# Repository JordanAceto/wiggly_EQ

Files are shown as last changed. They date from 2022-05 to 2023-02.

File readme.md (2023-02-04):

## Rackmount 3-Band Parametric EQ and Compression FX unit

### [SCHEMATIC](https://github.com/JordanAceto/wiggly_EQ/blob/main/construction_docs/wiggly_EQ_schematic.pdf)

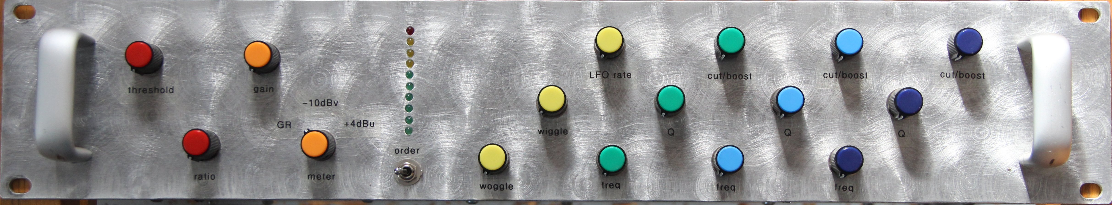
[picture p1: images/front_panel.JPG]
front panel


### Features:
#### 3 bands of Parametric EQ
- boost/cut control
- Q control
- Center frequency control
- Voltage controlled frequency for wiggly and swooshy modulation effects

#### Compression
- Nice THAT compressor
- Ratio control
- Threshold control
- Makeup gain

#### LFO
- Wiggles the EQ stages
- Also does amplitude modulation for tremolo

#### Expression pedal input
- Works as a Volume pedal
- Can also control the LFO rate

#### LED bar graph meter
- Can indicate compression gain reduction
- Can also indicate the audio level at -10dBv or +4dBu

### Notes:
- this is an old project that I built on pad-per-hole prototyping board. There is no PCB layout.
- I would probably do a few things differently today, but it does work well and sounds good.
- there are a few missing values, and some that I had to guess about, it's probably pretty close to right, but there might be some errors.
- there is a map of the protoboard IC locations as a troubleshooting and modification aid

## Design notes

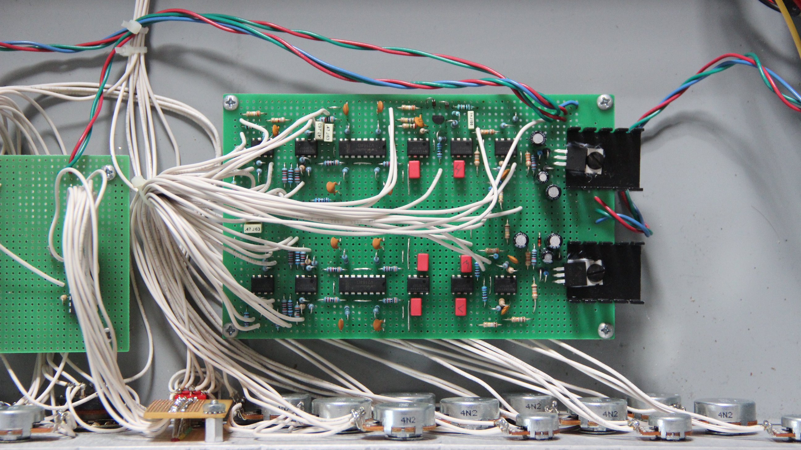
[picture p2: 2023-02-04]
images/eq_and_ps_board.JPG

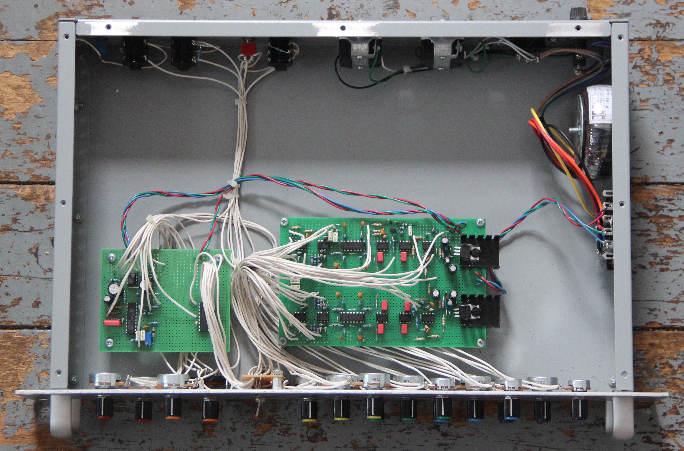
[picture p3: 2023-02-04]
images/guts_straight.JPG

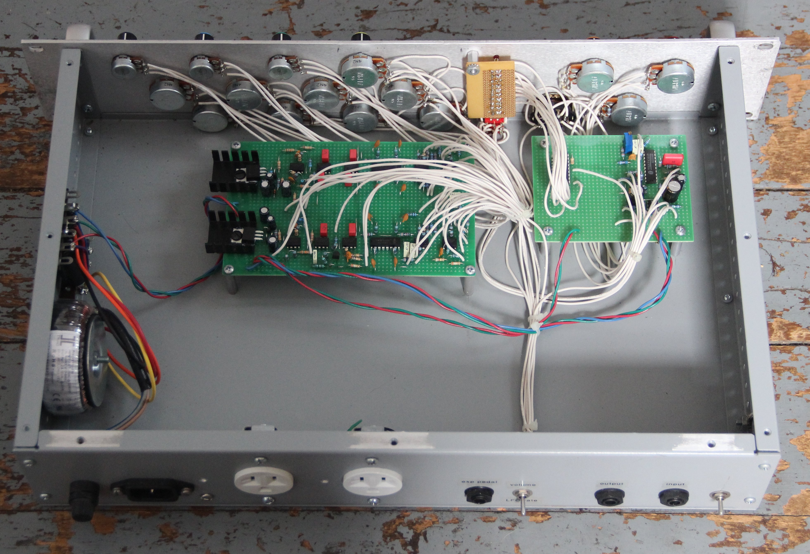
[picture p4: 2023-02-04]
images/guts_angle_2.JPG

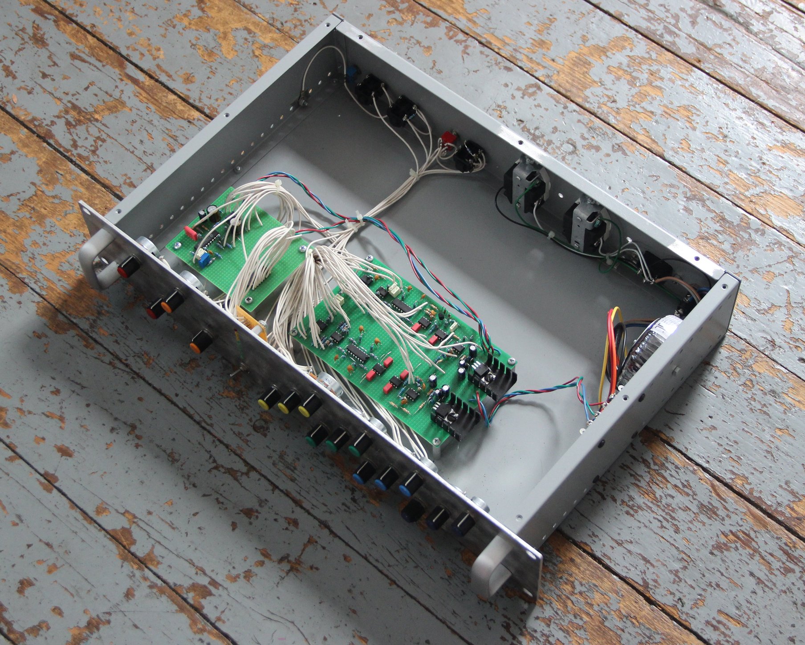
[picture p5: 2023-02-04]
images/guts_angle_1.JPG

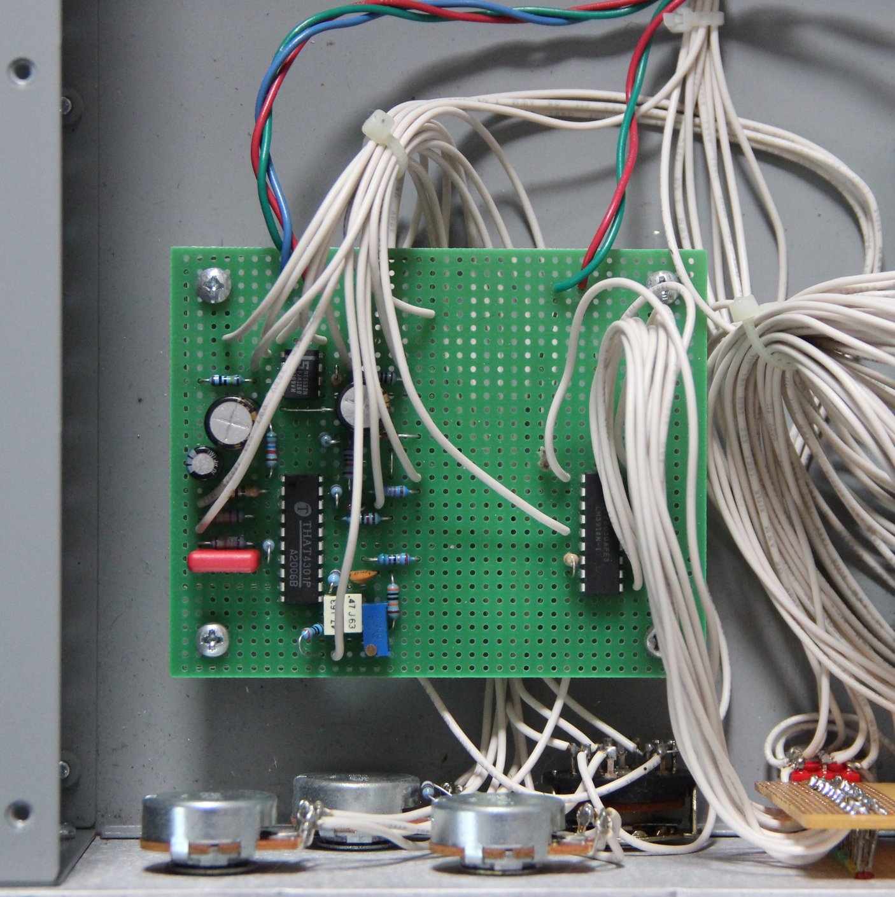
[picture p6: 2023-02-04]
images/compressor_board.JPG

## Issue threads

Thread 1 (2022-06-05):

Schematic has power supply error

JordanAceto, 2022-06-05:
The power supply schematic shows typical LM317/337 3-terminal regulators.

The connection between the V0 resistor and the ADJ pin is omitted on the schematic for both regulators.

This error should be fixed in the schematic.

The physical device is constructed correctly and works.

Closed 2022-08-01.

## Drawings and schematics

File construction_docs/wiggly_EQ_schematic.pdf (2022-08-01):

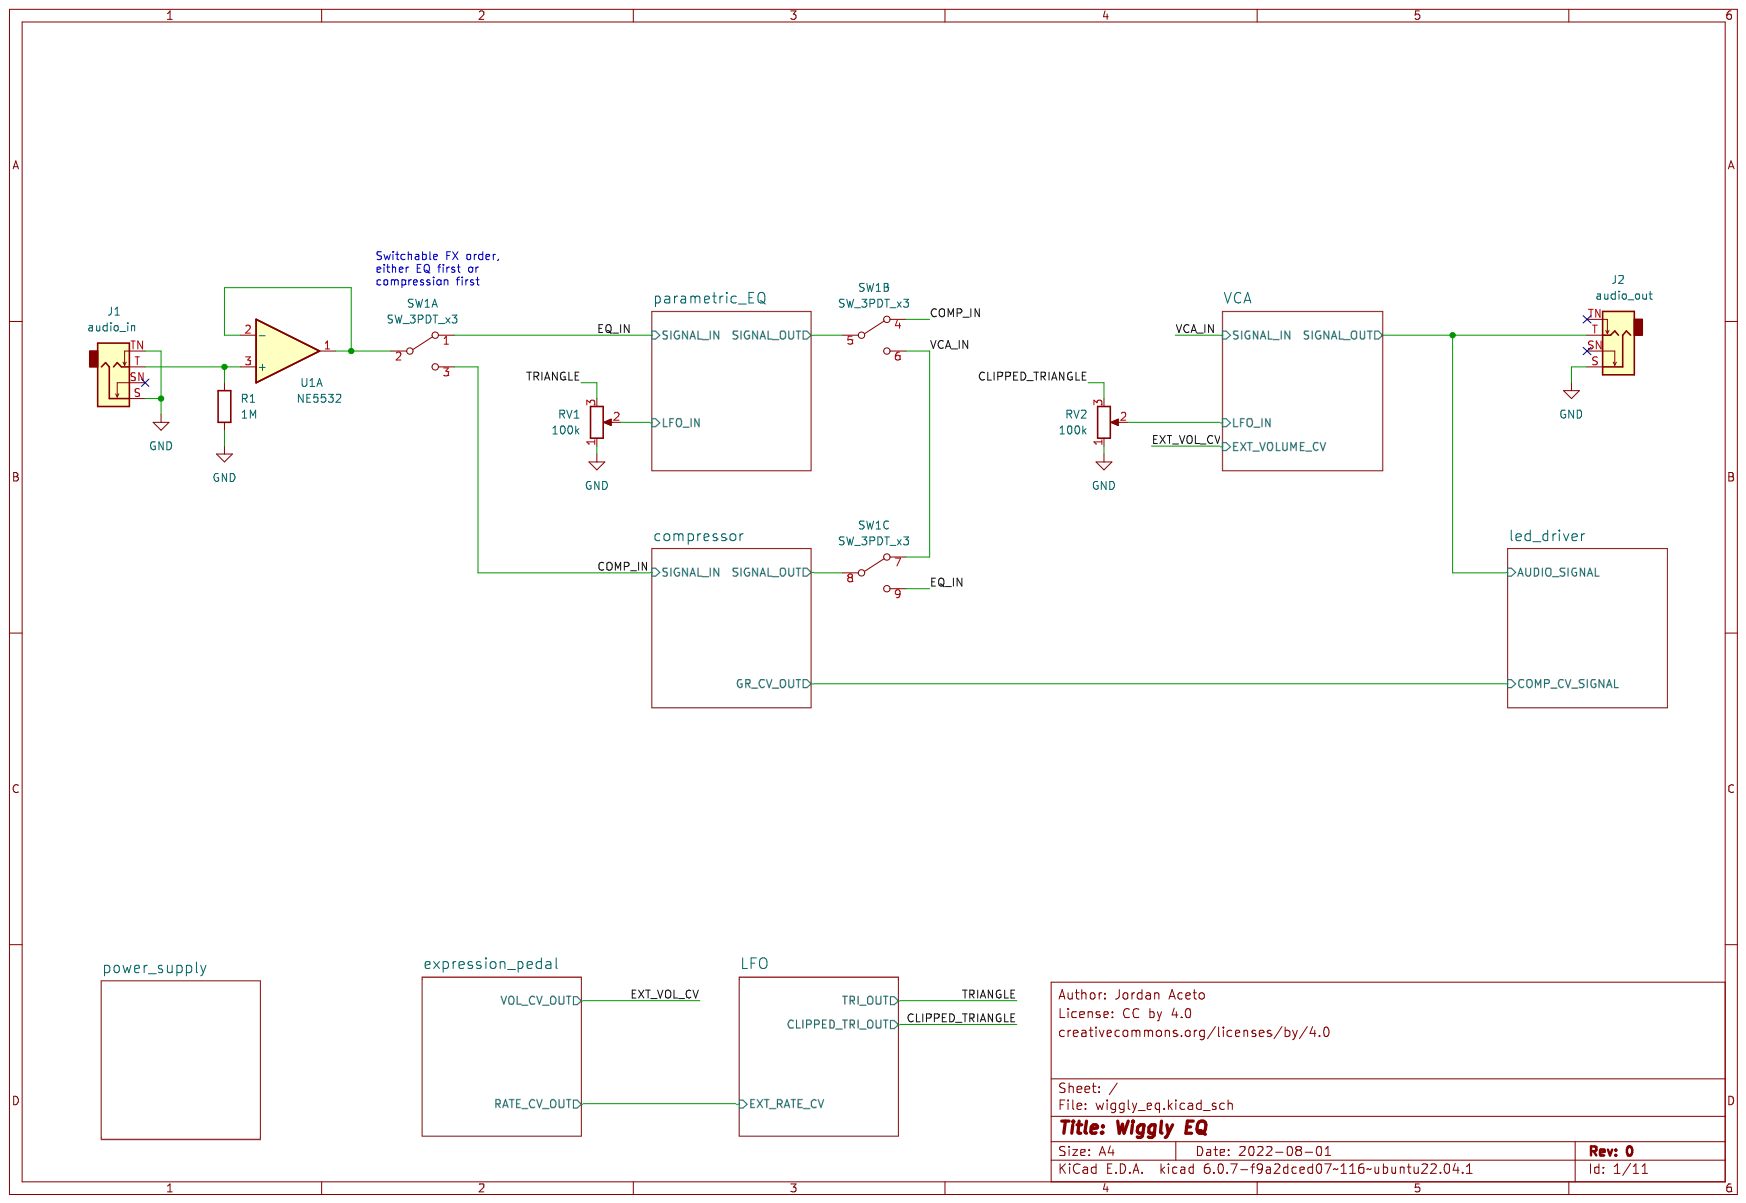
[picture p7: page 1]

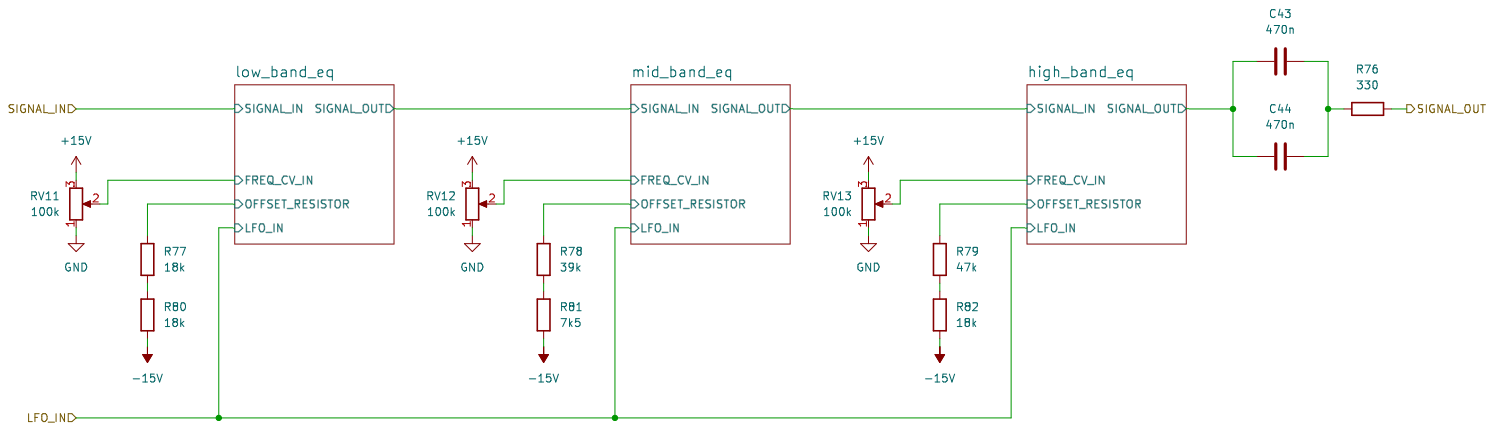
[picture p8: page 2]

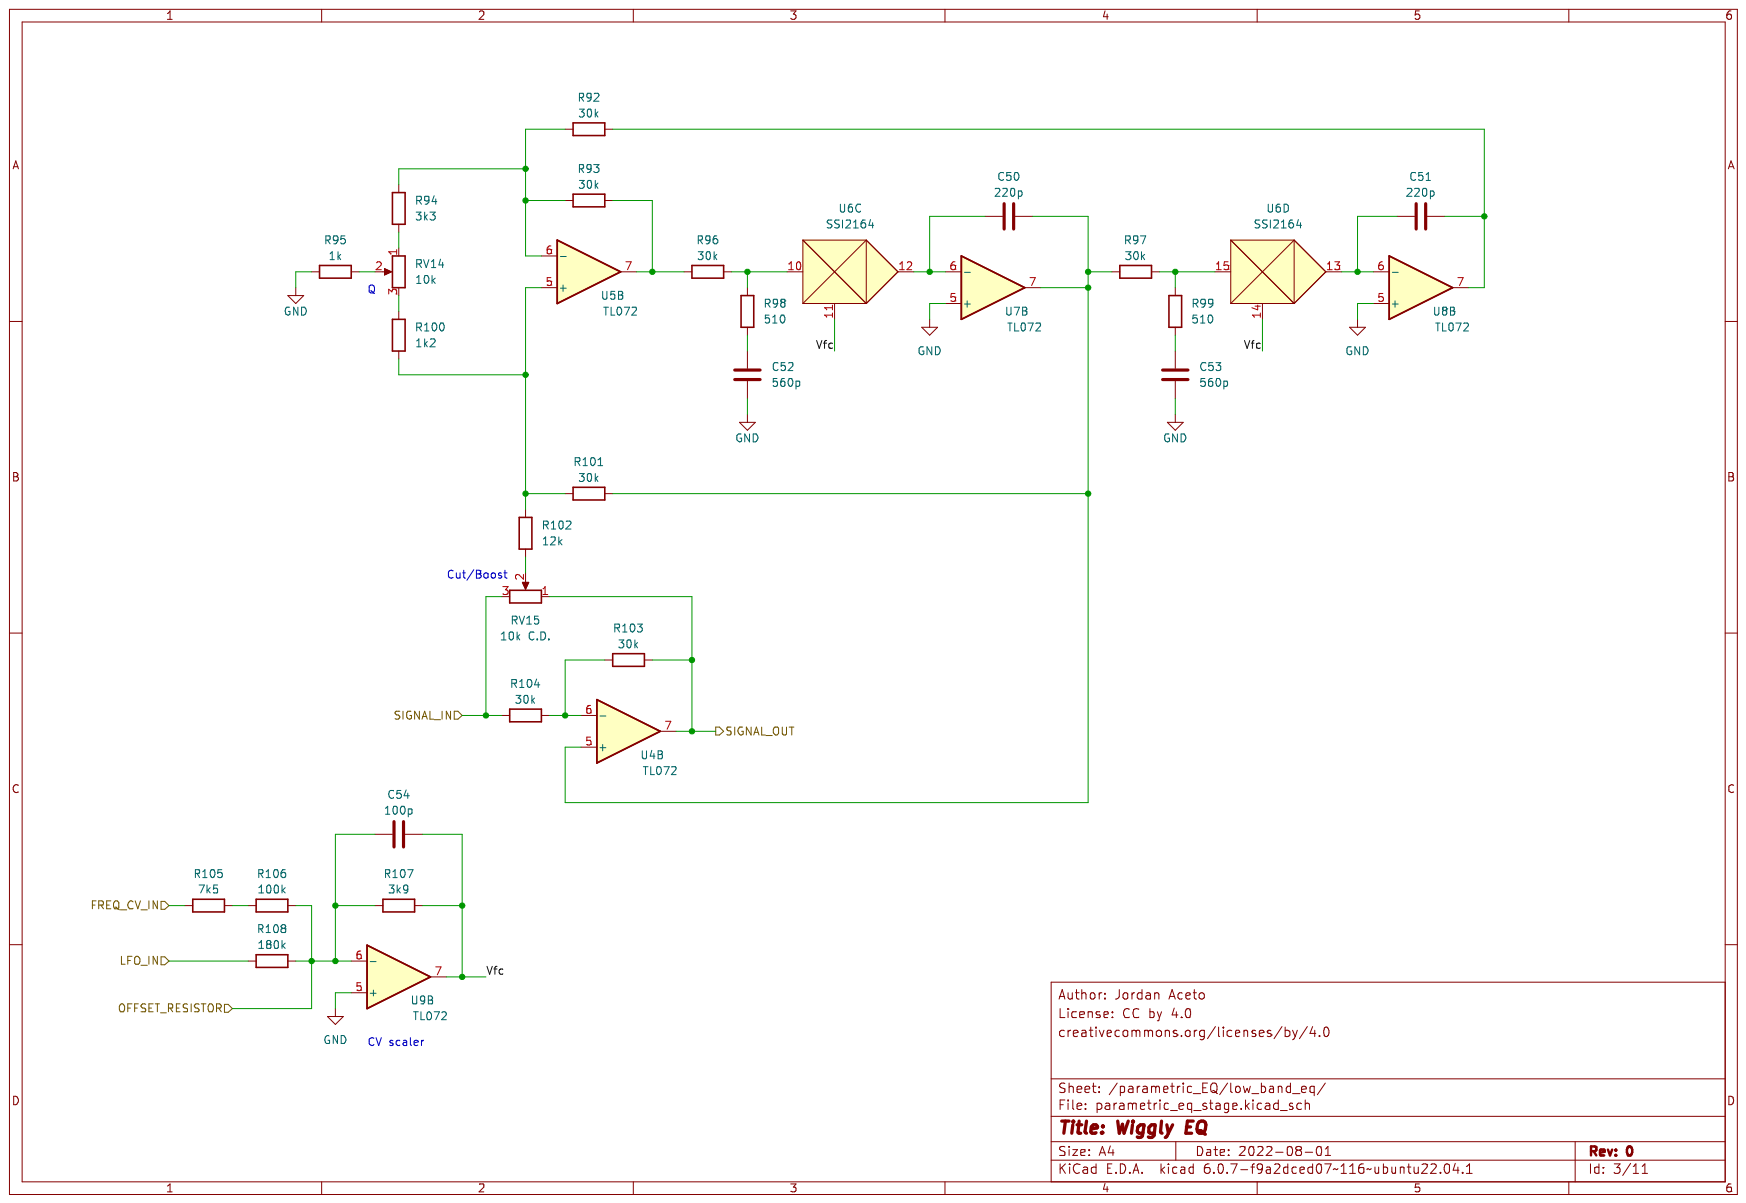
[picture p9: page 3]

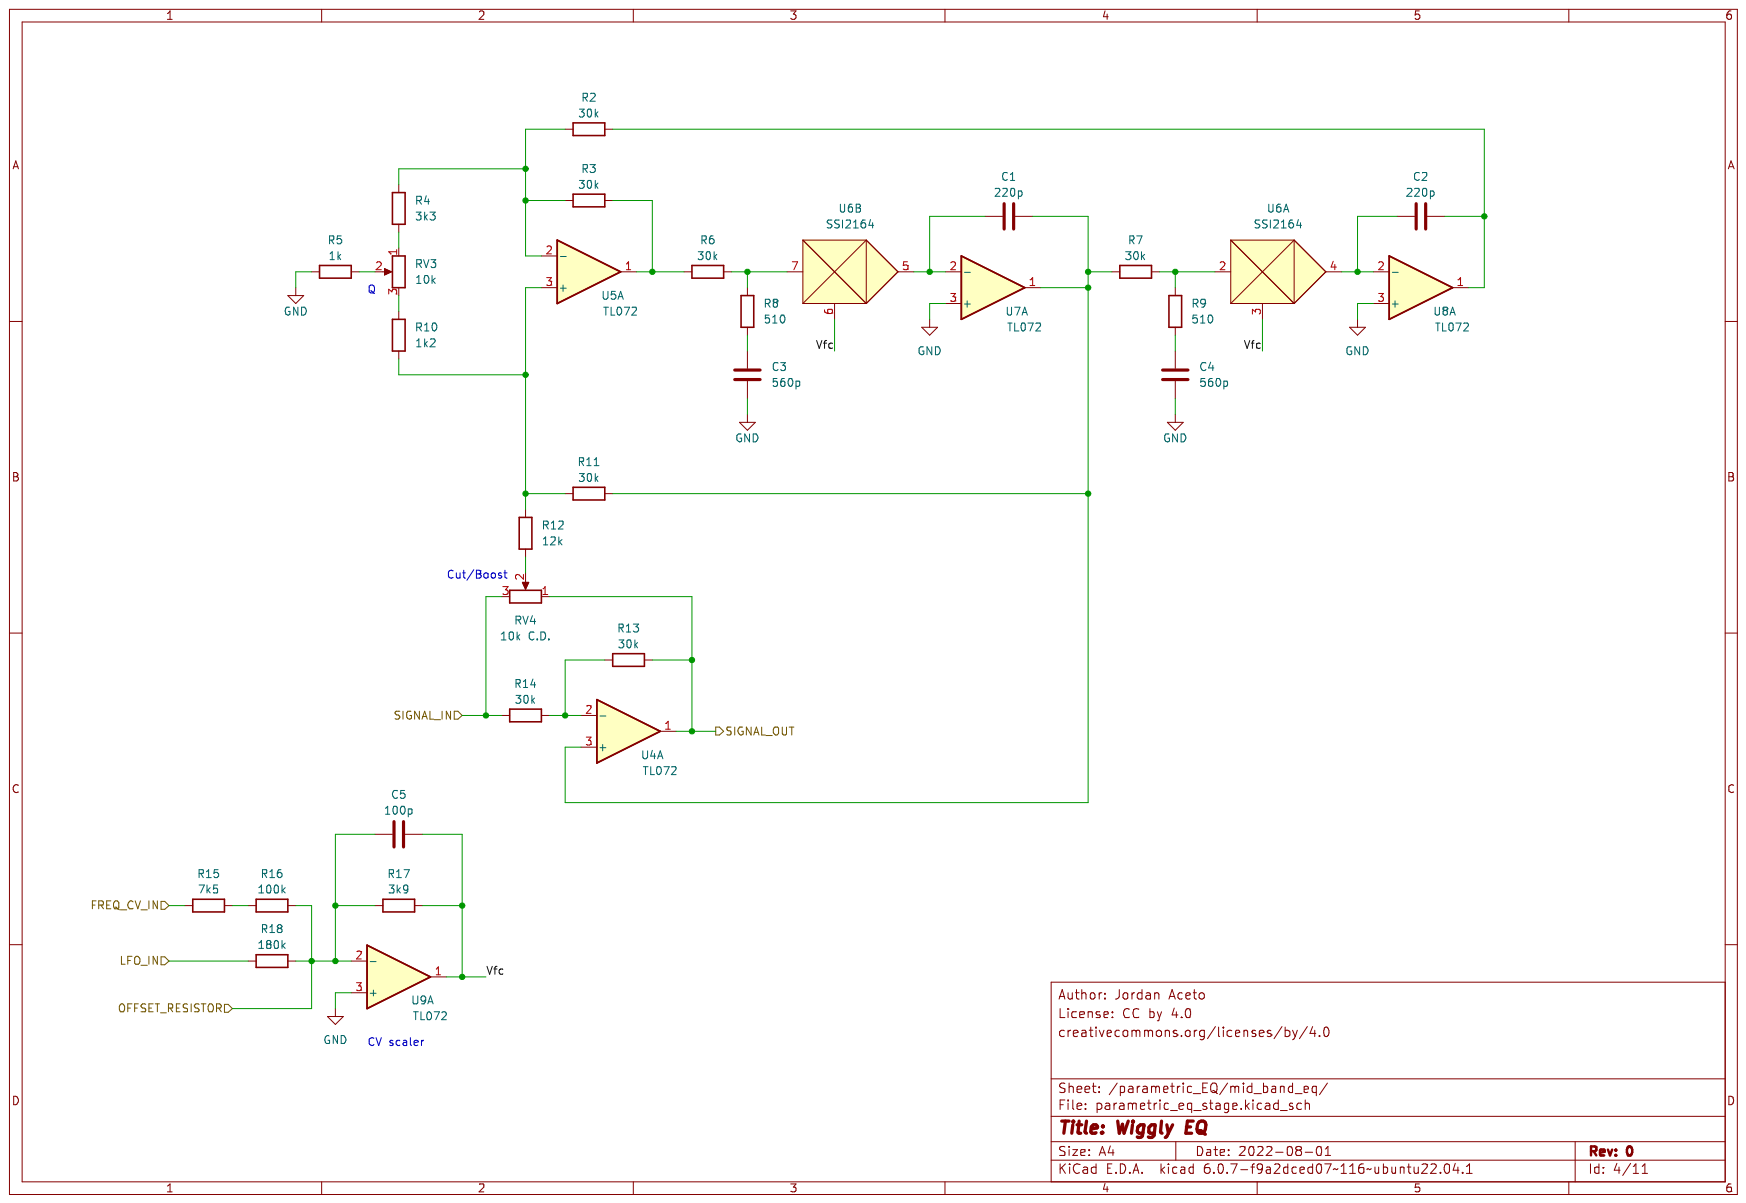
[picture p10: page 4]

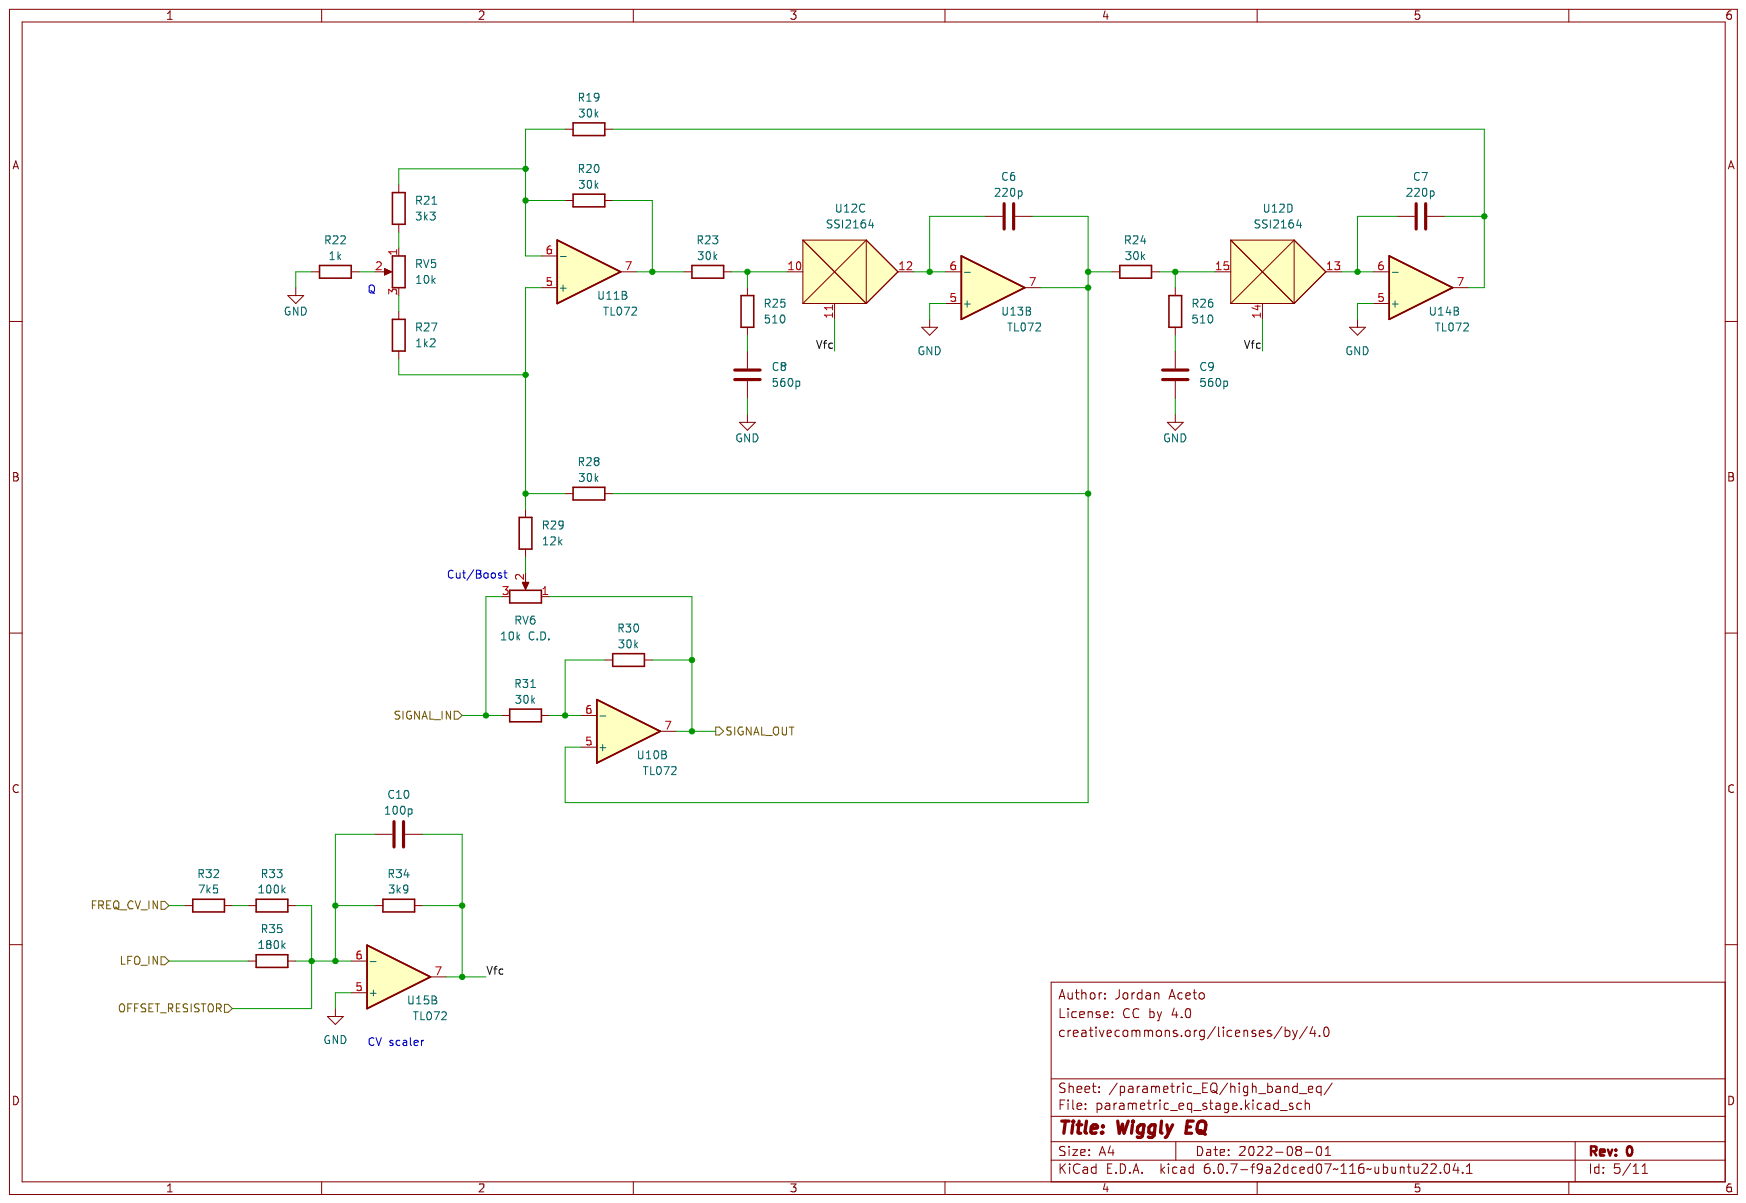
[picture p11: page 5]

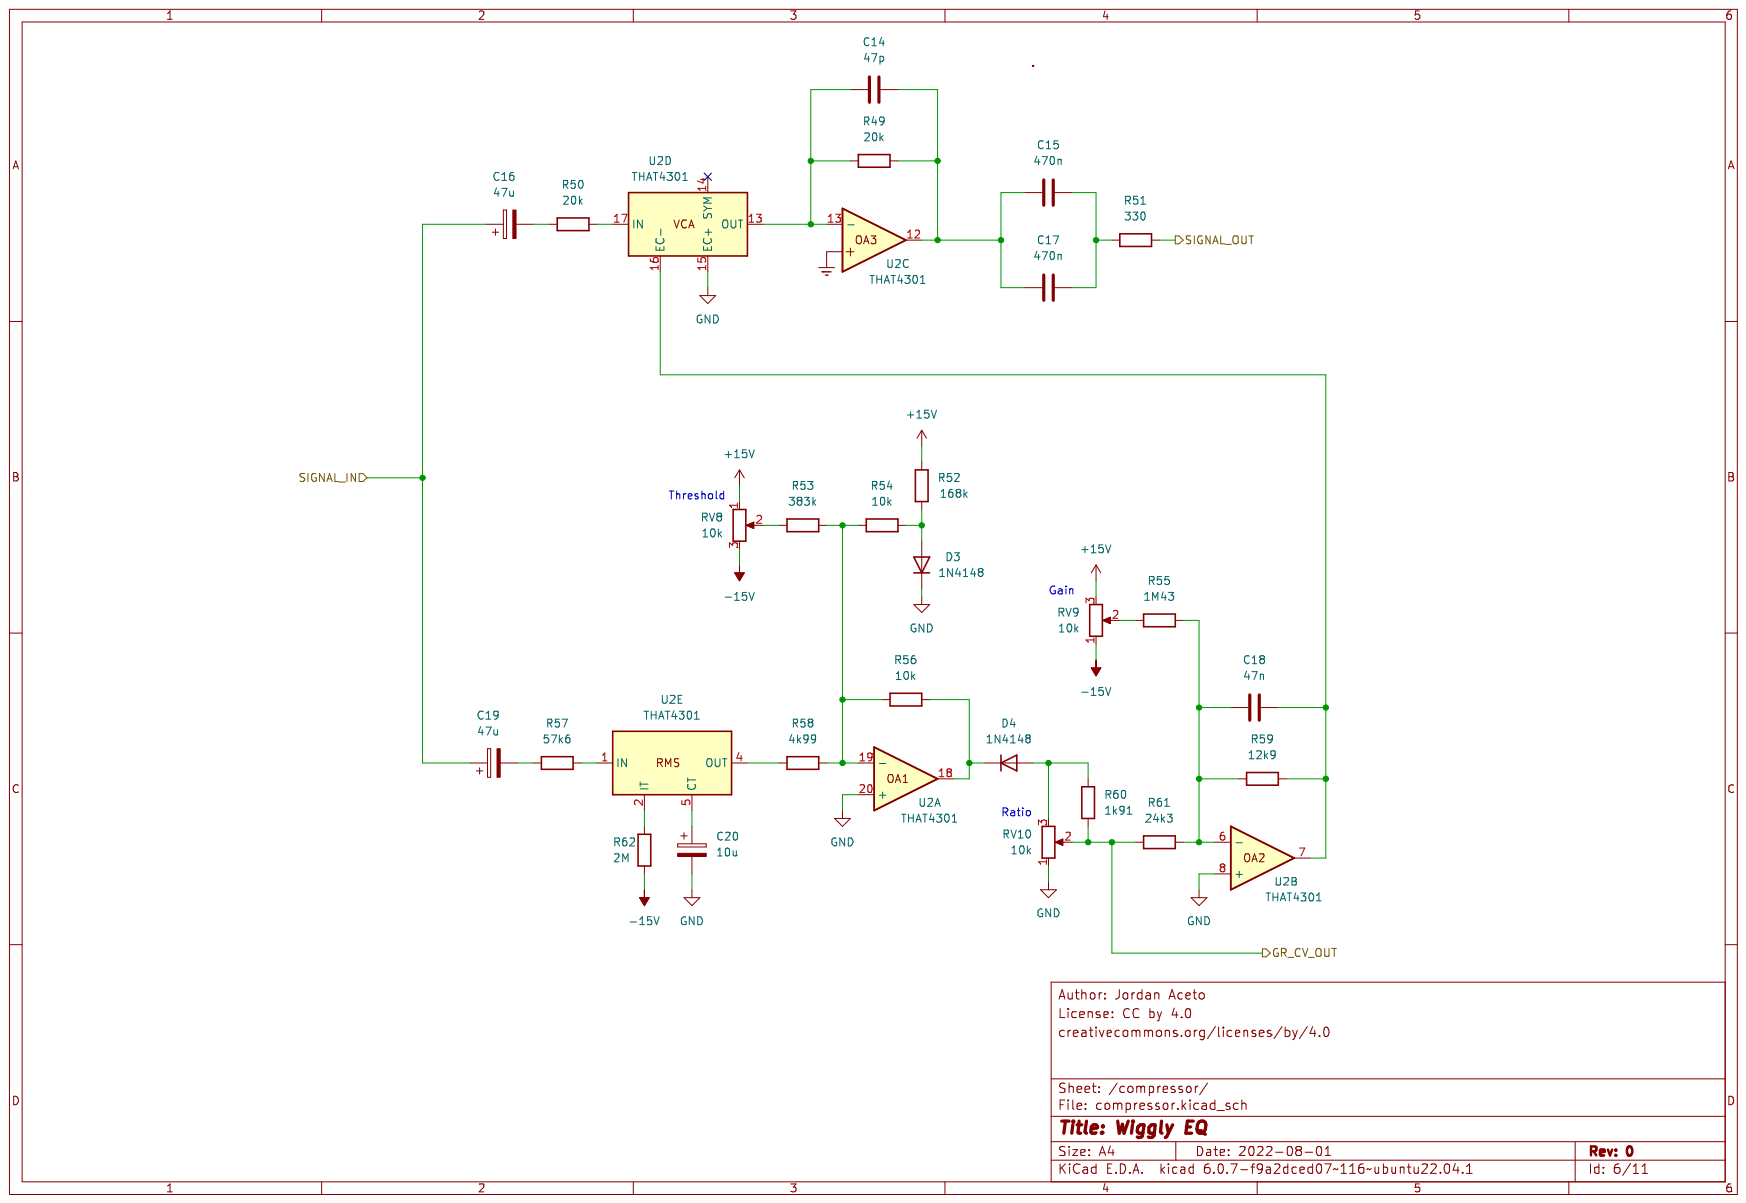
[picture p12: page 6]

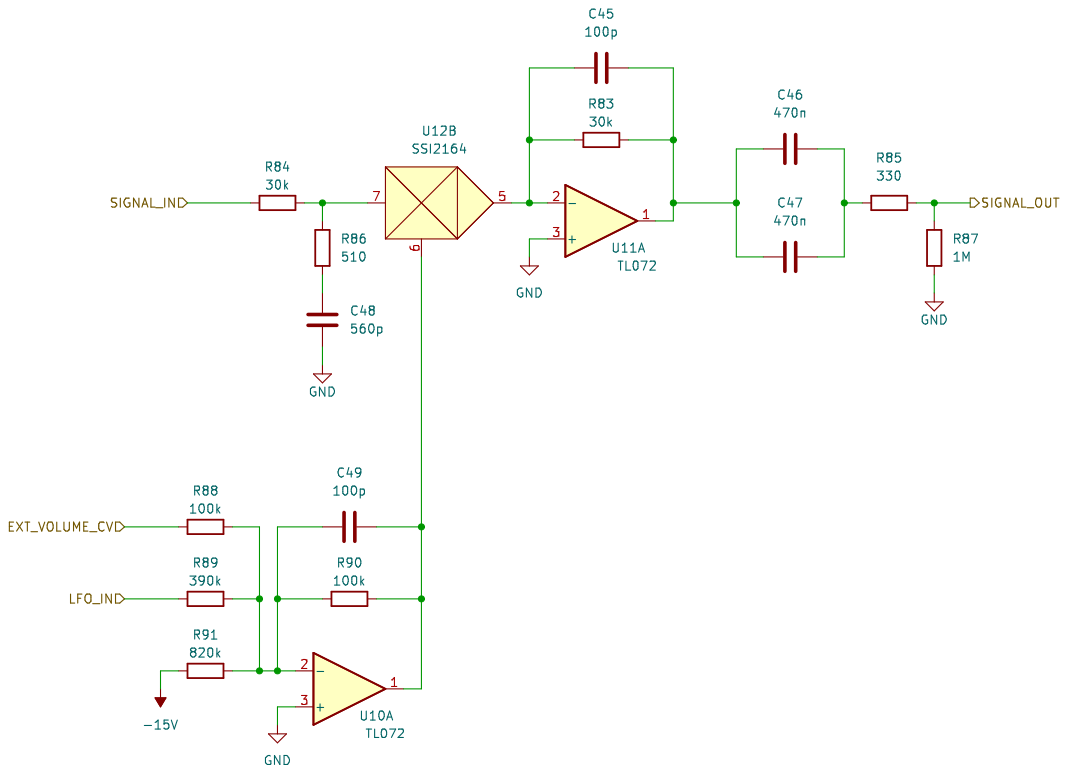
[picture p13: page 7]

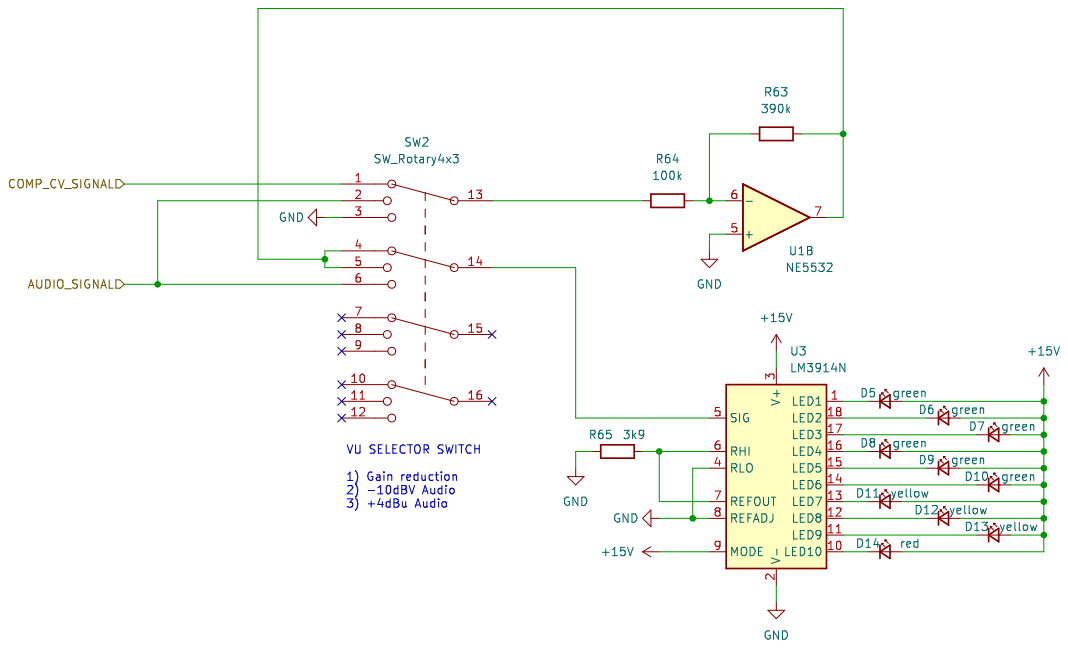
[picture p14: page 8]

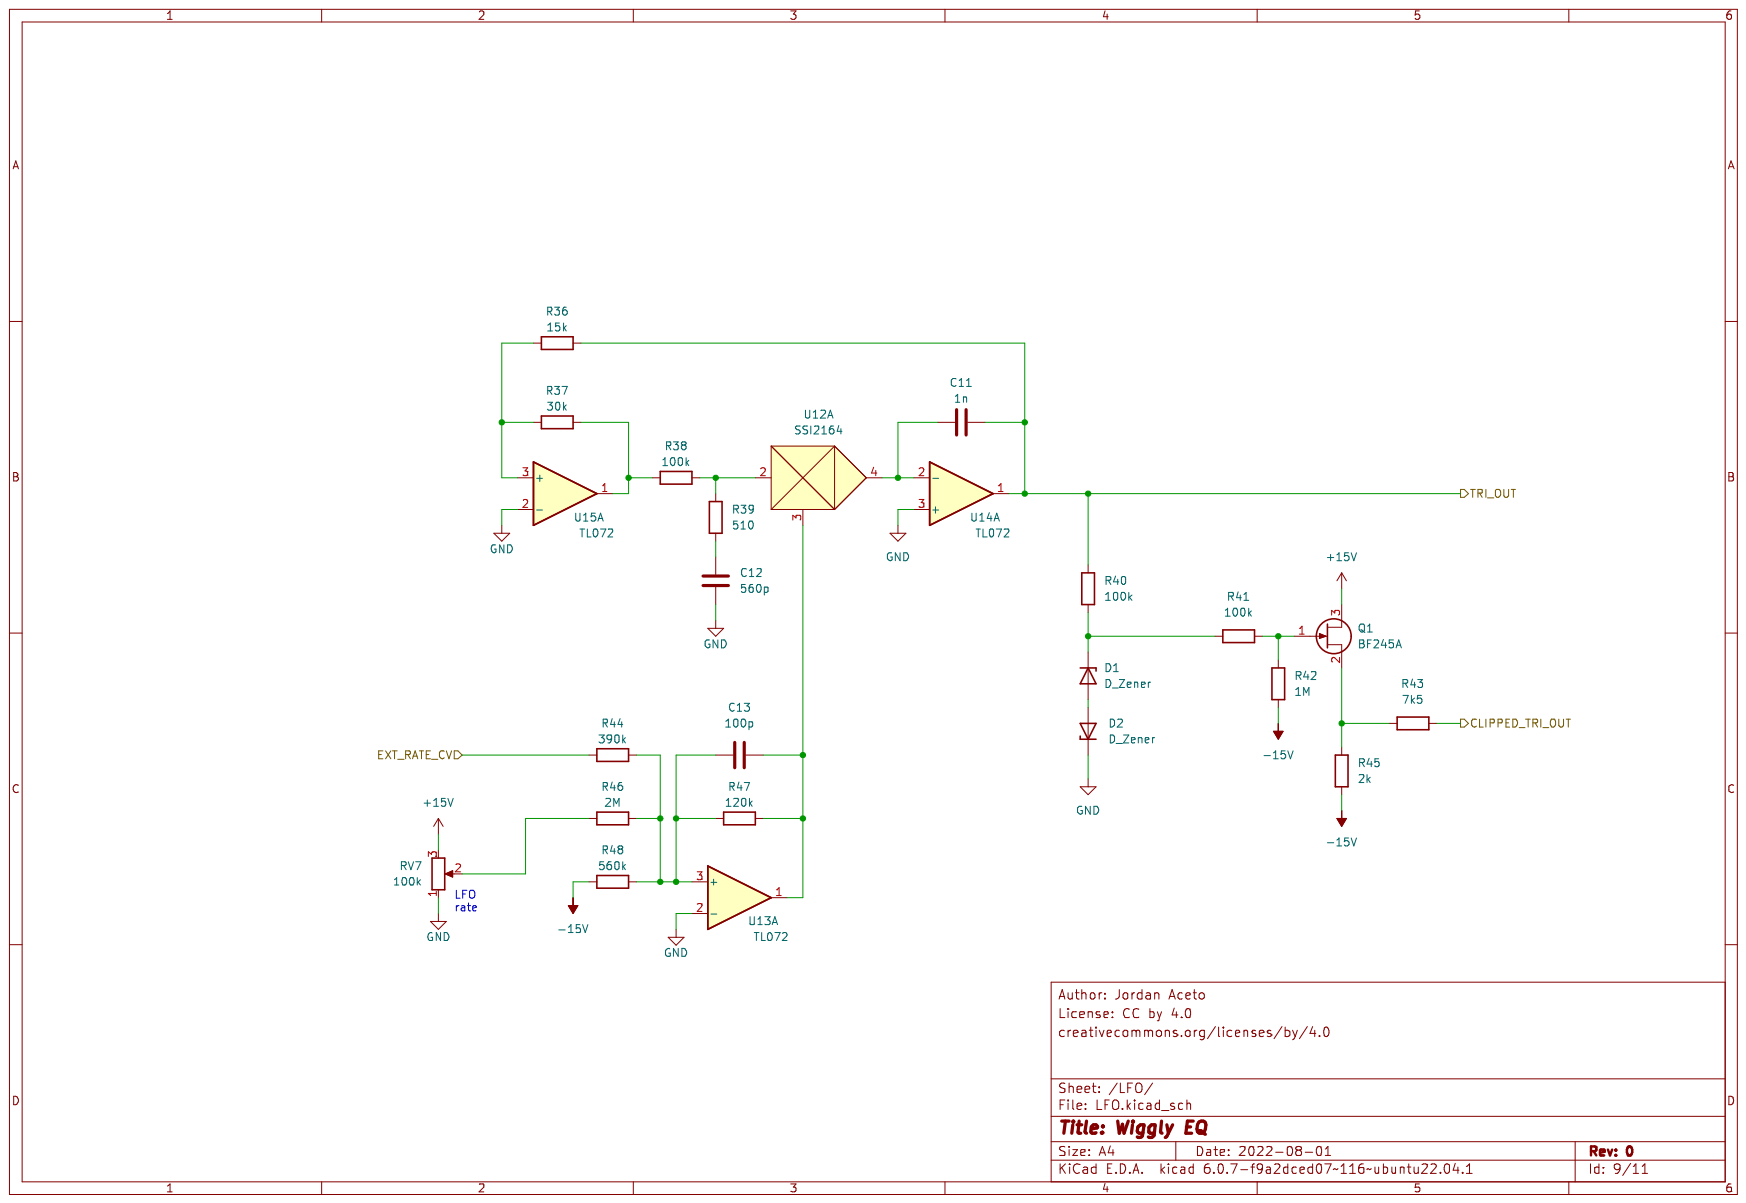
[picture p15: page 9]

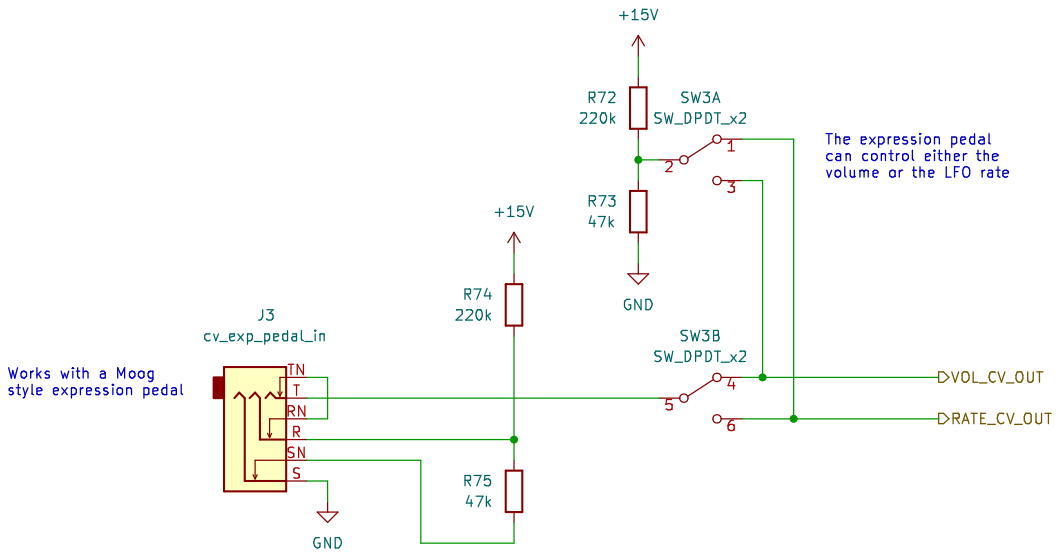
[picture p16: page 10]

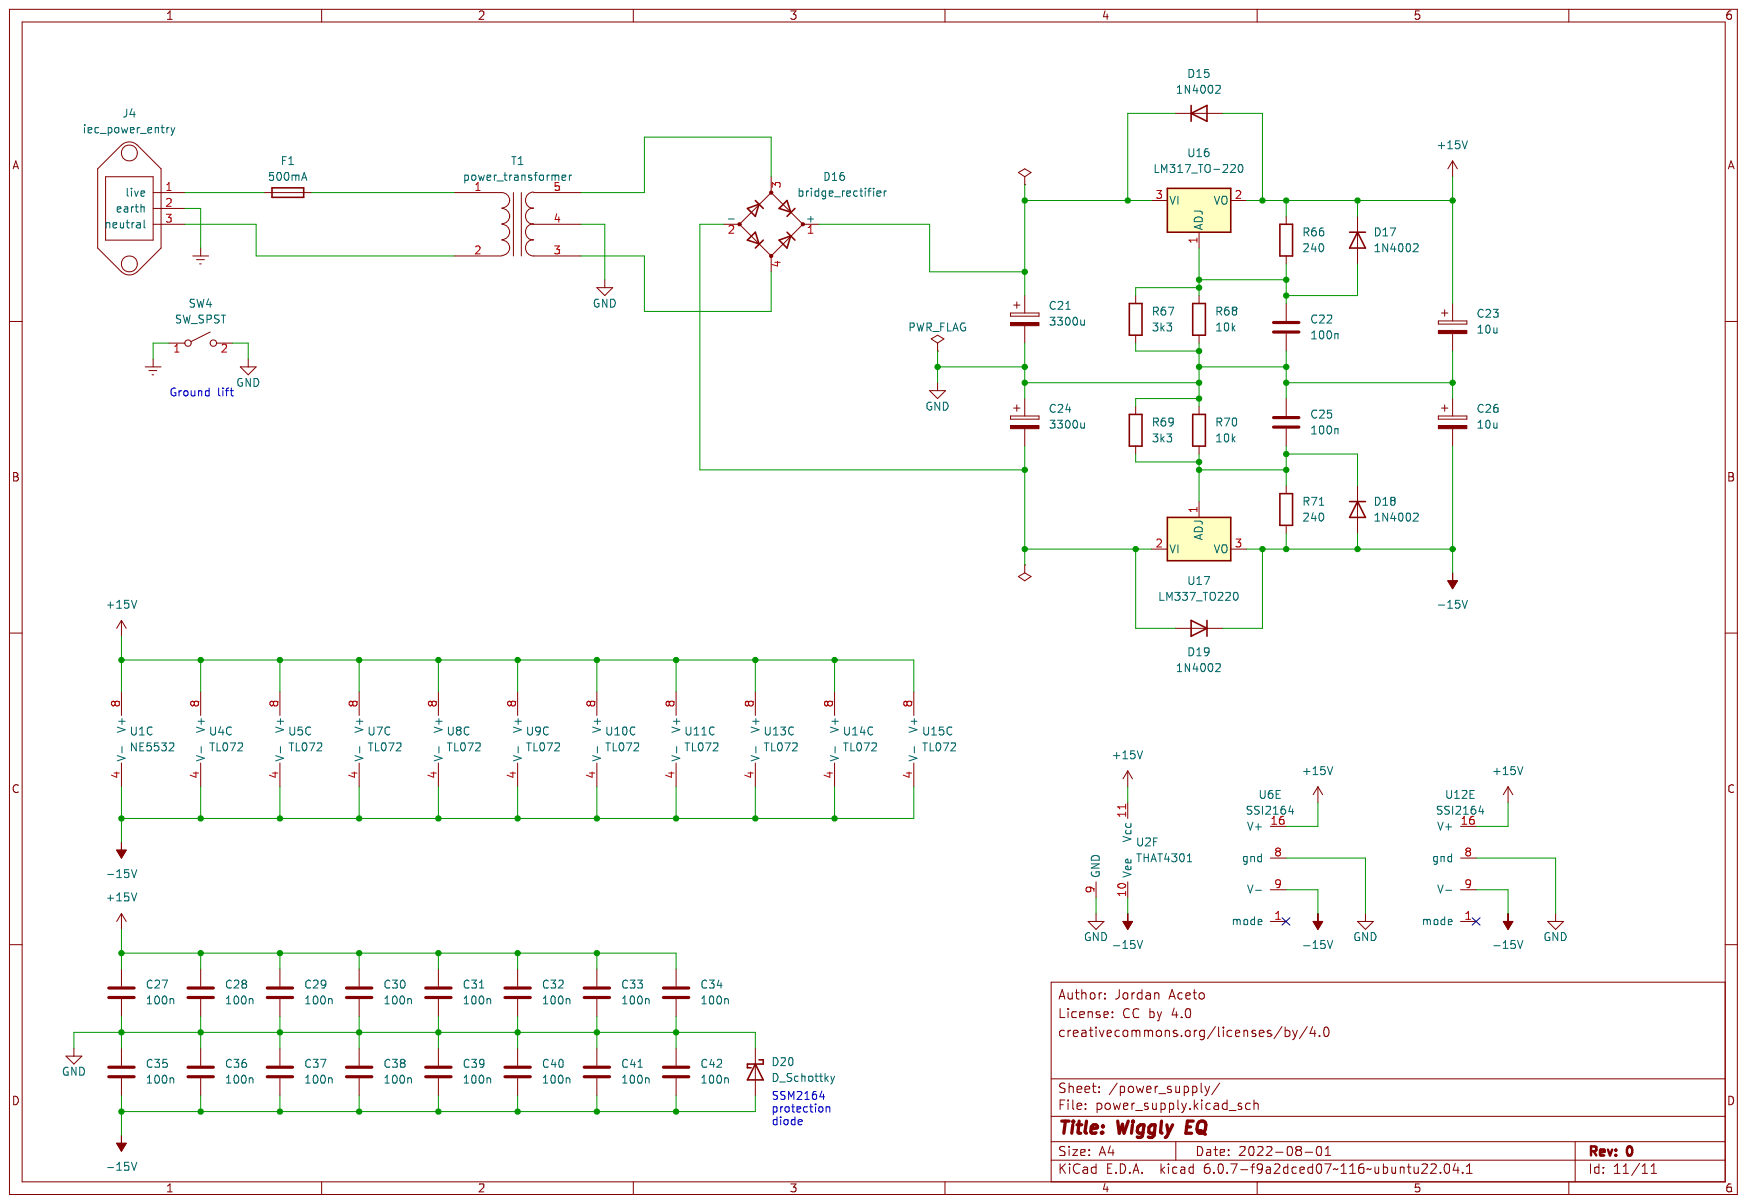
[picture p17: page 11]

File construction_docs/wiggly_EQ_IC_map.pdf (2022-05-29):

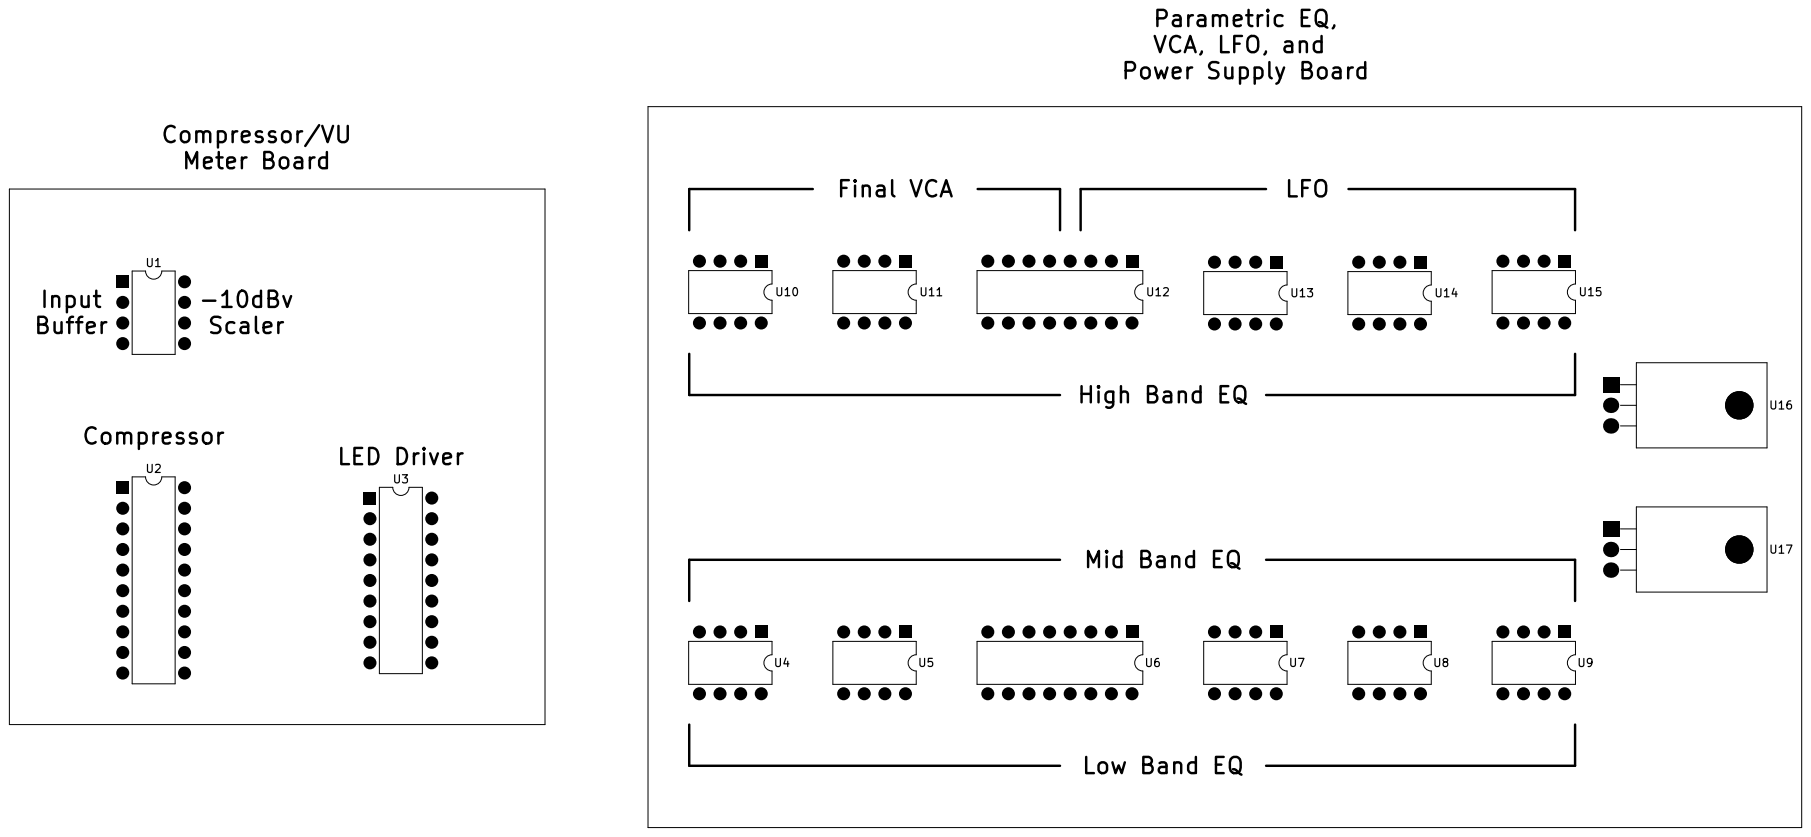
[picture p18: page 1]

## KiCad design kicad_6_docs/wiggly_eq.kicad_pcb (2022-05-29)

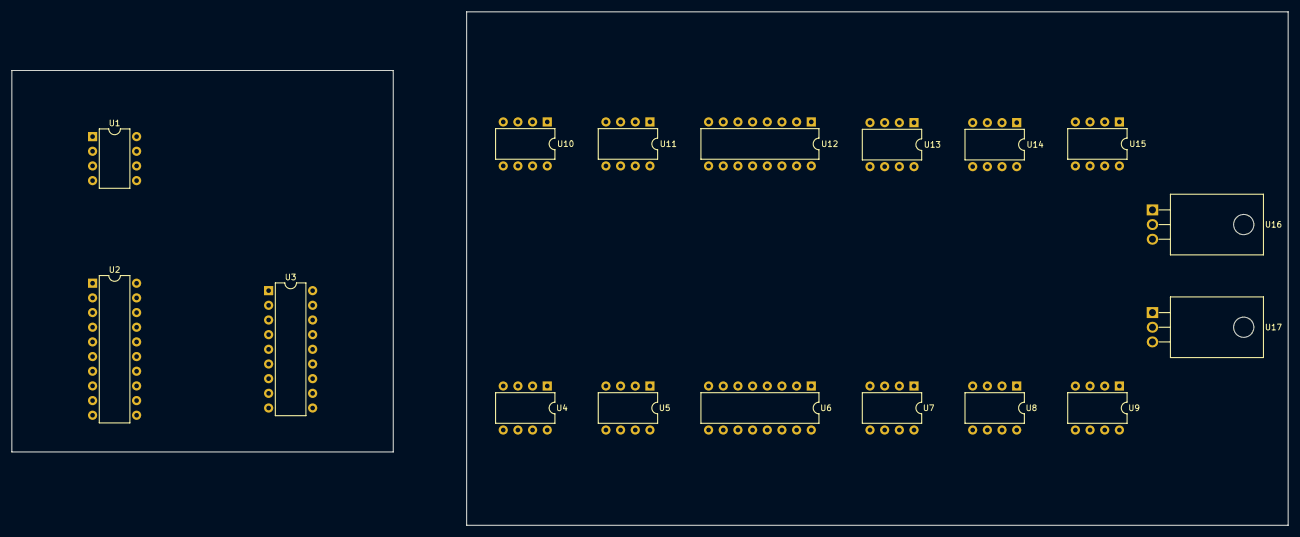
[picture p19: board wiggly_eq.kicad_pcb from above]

Board: 2 copper layers, 142.2 x 88.9 mm, 17 parts (0 on the bottom side), 22 nets, no tracks yet.

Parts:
U1: NE5532; DIP-8_W7.62mm
U2: THAT4301; DIP-20_W7.62mm
U3: LM3914N; DIP-18_W7.62mm
U4, U5, U7, U8, U9, U10, U11, U13, U14, U15: TL072; DIP-8_W7.62mm
U6, U12: SSI2164; DIP-16_W7.62mm
U16: LM317_TO-220; TO-220F-3_Horizontal_TabDown
U17: LM337_TO220; TO-220F-3_Horizontal_TabDown

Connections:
+15V: U1.8 (V+), U2.11 (Vcc), U3.3 (V+), U3.9 (MODE), U4.8 (V+), U5.8 (V+), U6.16 (V+), U7.8 (V+), U8.8 (V+), U9.8 (V+), U10.8 (V+), U11.8 (V+), U12.16 (V+), U13.8 (V+), U14.8 (V+), U15.8 (V+), U16.2 (VO)
-15V: U1.4 (V-), U2.10 (Vee), U4.4 (V-), U5.4 (V-), U6.9 (V-), U7.4 (V-), U8.4 (V-), U9.4 (V-), U10.4 (V-), U11.4 (V-), U12.9 (V-), U13.4 (V-), U14.4 (V-), U15.4 (V-), U17.3 (VO)
/parametric_EQ/high_band_eq/Vfc: U12.11, U12.14, U15.7
/parametric_EQ/low_band_eq/Vfc: U6.11, U6.14, U9.7
/parametric_EQ/mid_band_eq/Vfc: U6.3, U6.6, U9.1
GND: U1.5 (+), U2.8 (+), U2.9 (GND), U2.15 (EC+), U2.20 (+), U3.2 (V-), U3.4 (RLO), U3.8 (REFADJ), U6.8 (gnd), U7.3 (+), U7.5 (+), U8.3 (+), U8.5 (+), U9.3 (+), U9.5 (+), U10.3 (+), U11.3 (+), U12.8 (gnd), U13.2 (-), U13.5 (+), U14.3 (+), U14.5 (+), U15.2 (-), U15.5 (+)
unnamed: U6.5, U7.2 (-)
unnamed: U4.3 (+), U7.1
unnamed: U6.4, U8.2 (-)
unnamed: U12.12, U13.6 (-)
unnamed: U10.5 (+), U13.7
unnamed: U12.13, U14.6 (-)
unnamed: U12.4, U14.2 (-)
unnamed: U12.3, U13.1
unnamed: U2.7, U2.16 (EC-)
unnamed: U11.2 (-), U12.5
unnamed: U10.1, U12.6
unnamed: U6.12, U7.6 (-)
unnamed: U4.5 (+), U7.7
unnamed: U6.13, U8.6 (-)
unnamed: U3.6 (RHI), U3.7 (REFOUT)
unnamed: U1.1, U1.2 (-)

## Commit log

2022-05-29 Fix schematic link
2022-08-01 Fix power supply errors, tidy up schematic
    [LFO.kicad_sch, VCA.kicad_sch, compressor.kicad_sch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]

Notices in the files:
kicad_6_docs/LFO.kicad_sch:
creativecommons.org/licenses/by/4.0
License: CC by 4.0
